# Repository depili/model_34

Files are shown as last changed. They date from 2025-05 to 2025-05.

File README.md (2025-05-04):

# Files for Model 34 tape and card punch control

The circuit is based on the example in the manual. This repository includes the hardware as a kicad project, the software for the arduino for usb serial communications and a 3d printable drive belt replacement.

The belt was printed in TPU and seems to last well, at least in light use.

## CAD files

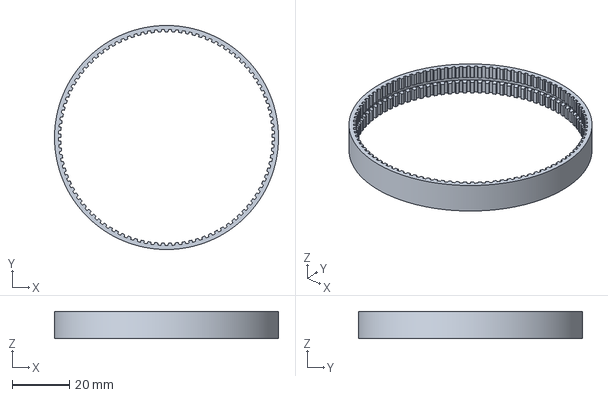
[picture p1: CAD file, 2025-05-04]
drive_belt/belt-corrected.FCStd
78.2 x 78.2 x 9.50 mm

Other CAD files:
drive_belt/belt-corrected-belt-loop.3mf

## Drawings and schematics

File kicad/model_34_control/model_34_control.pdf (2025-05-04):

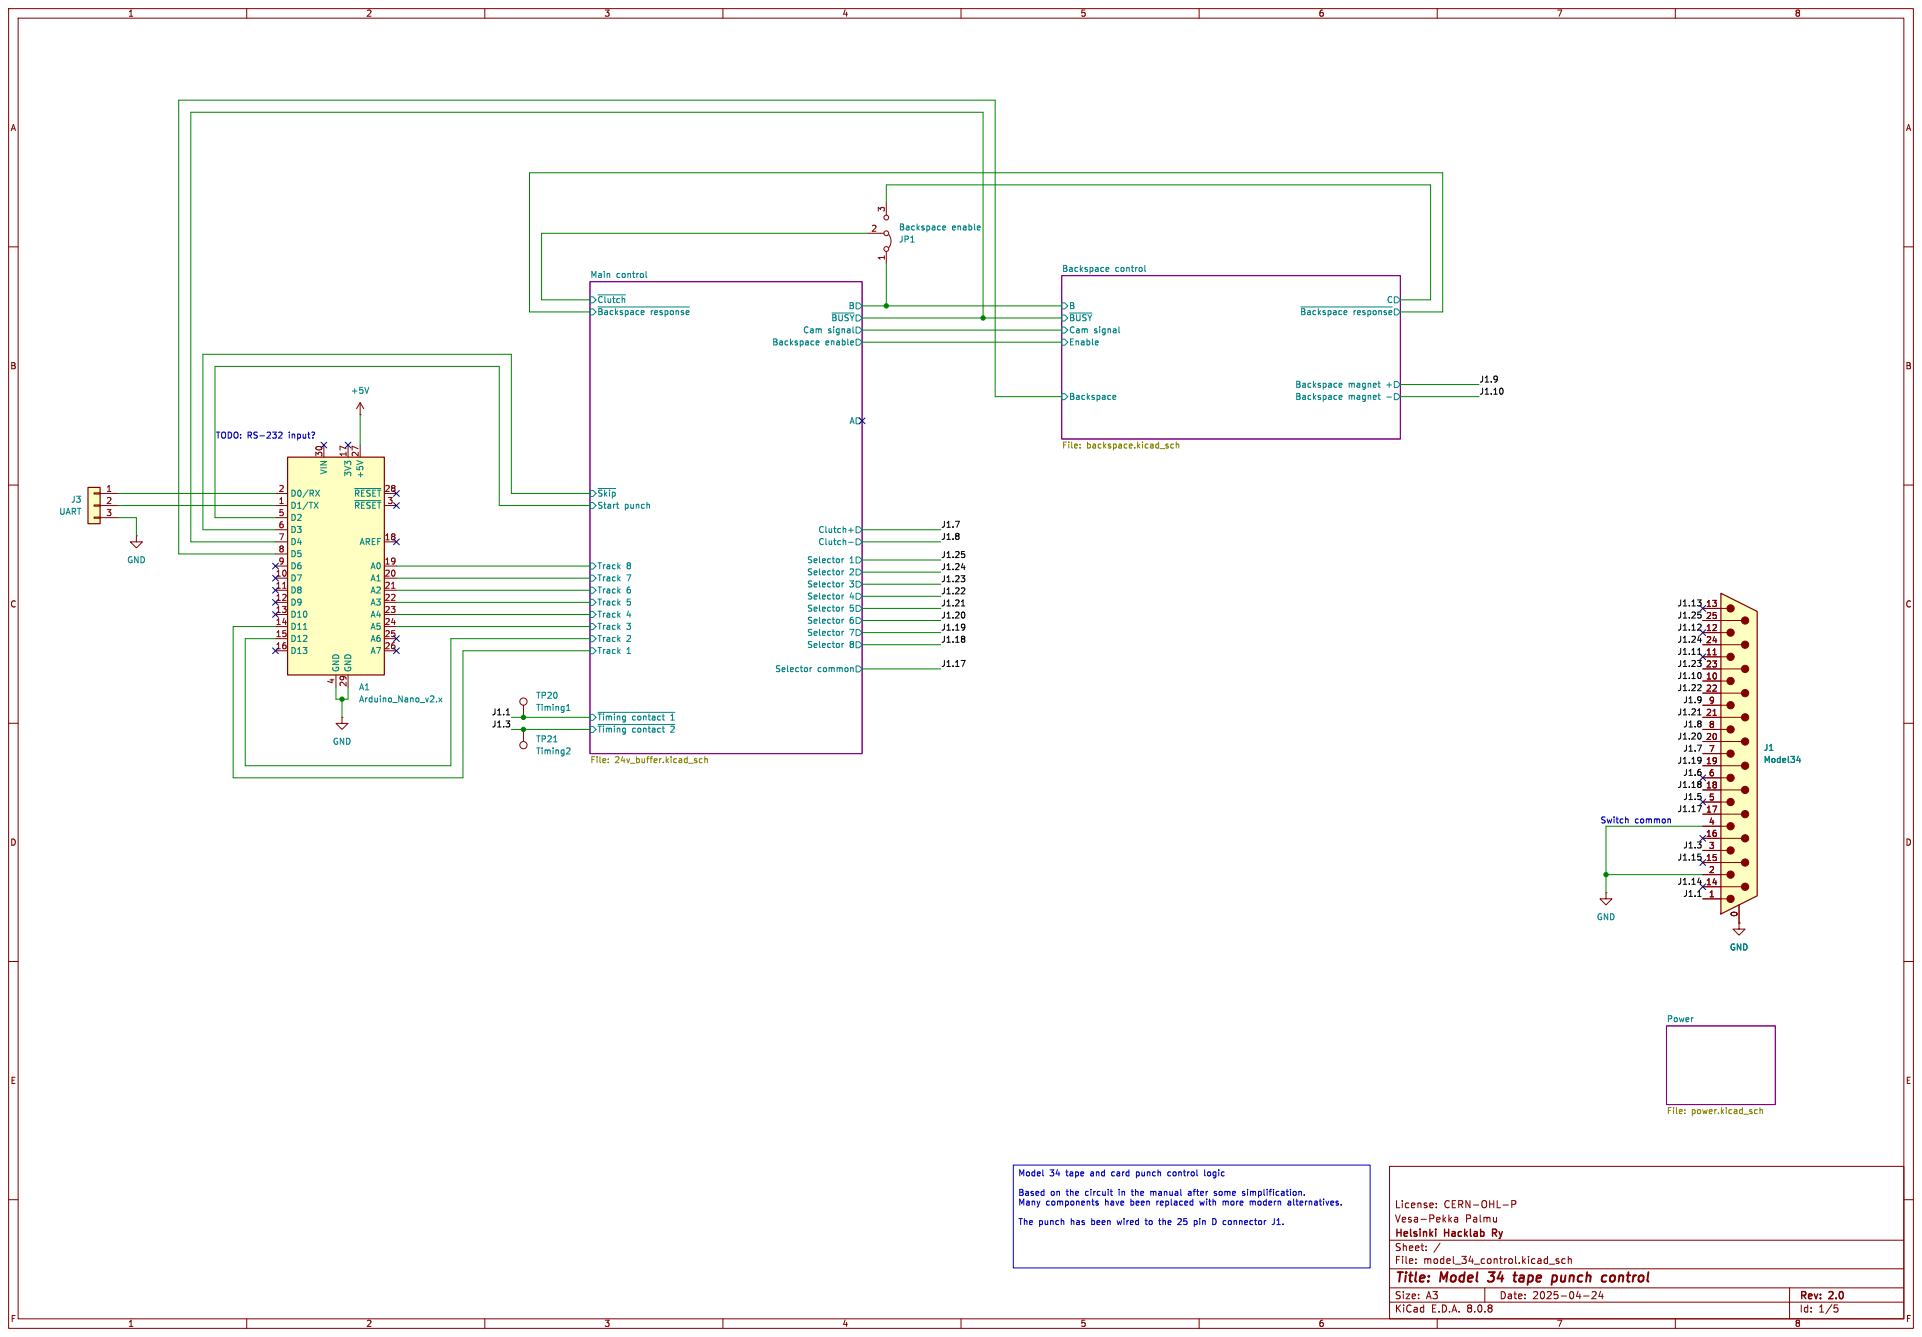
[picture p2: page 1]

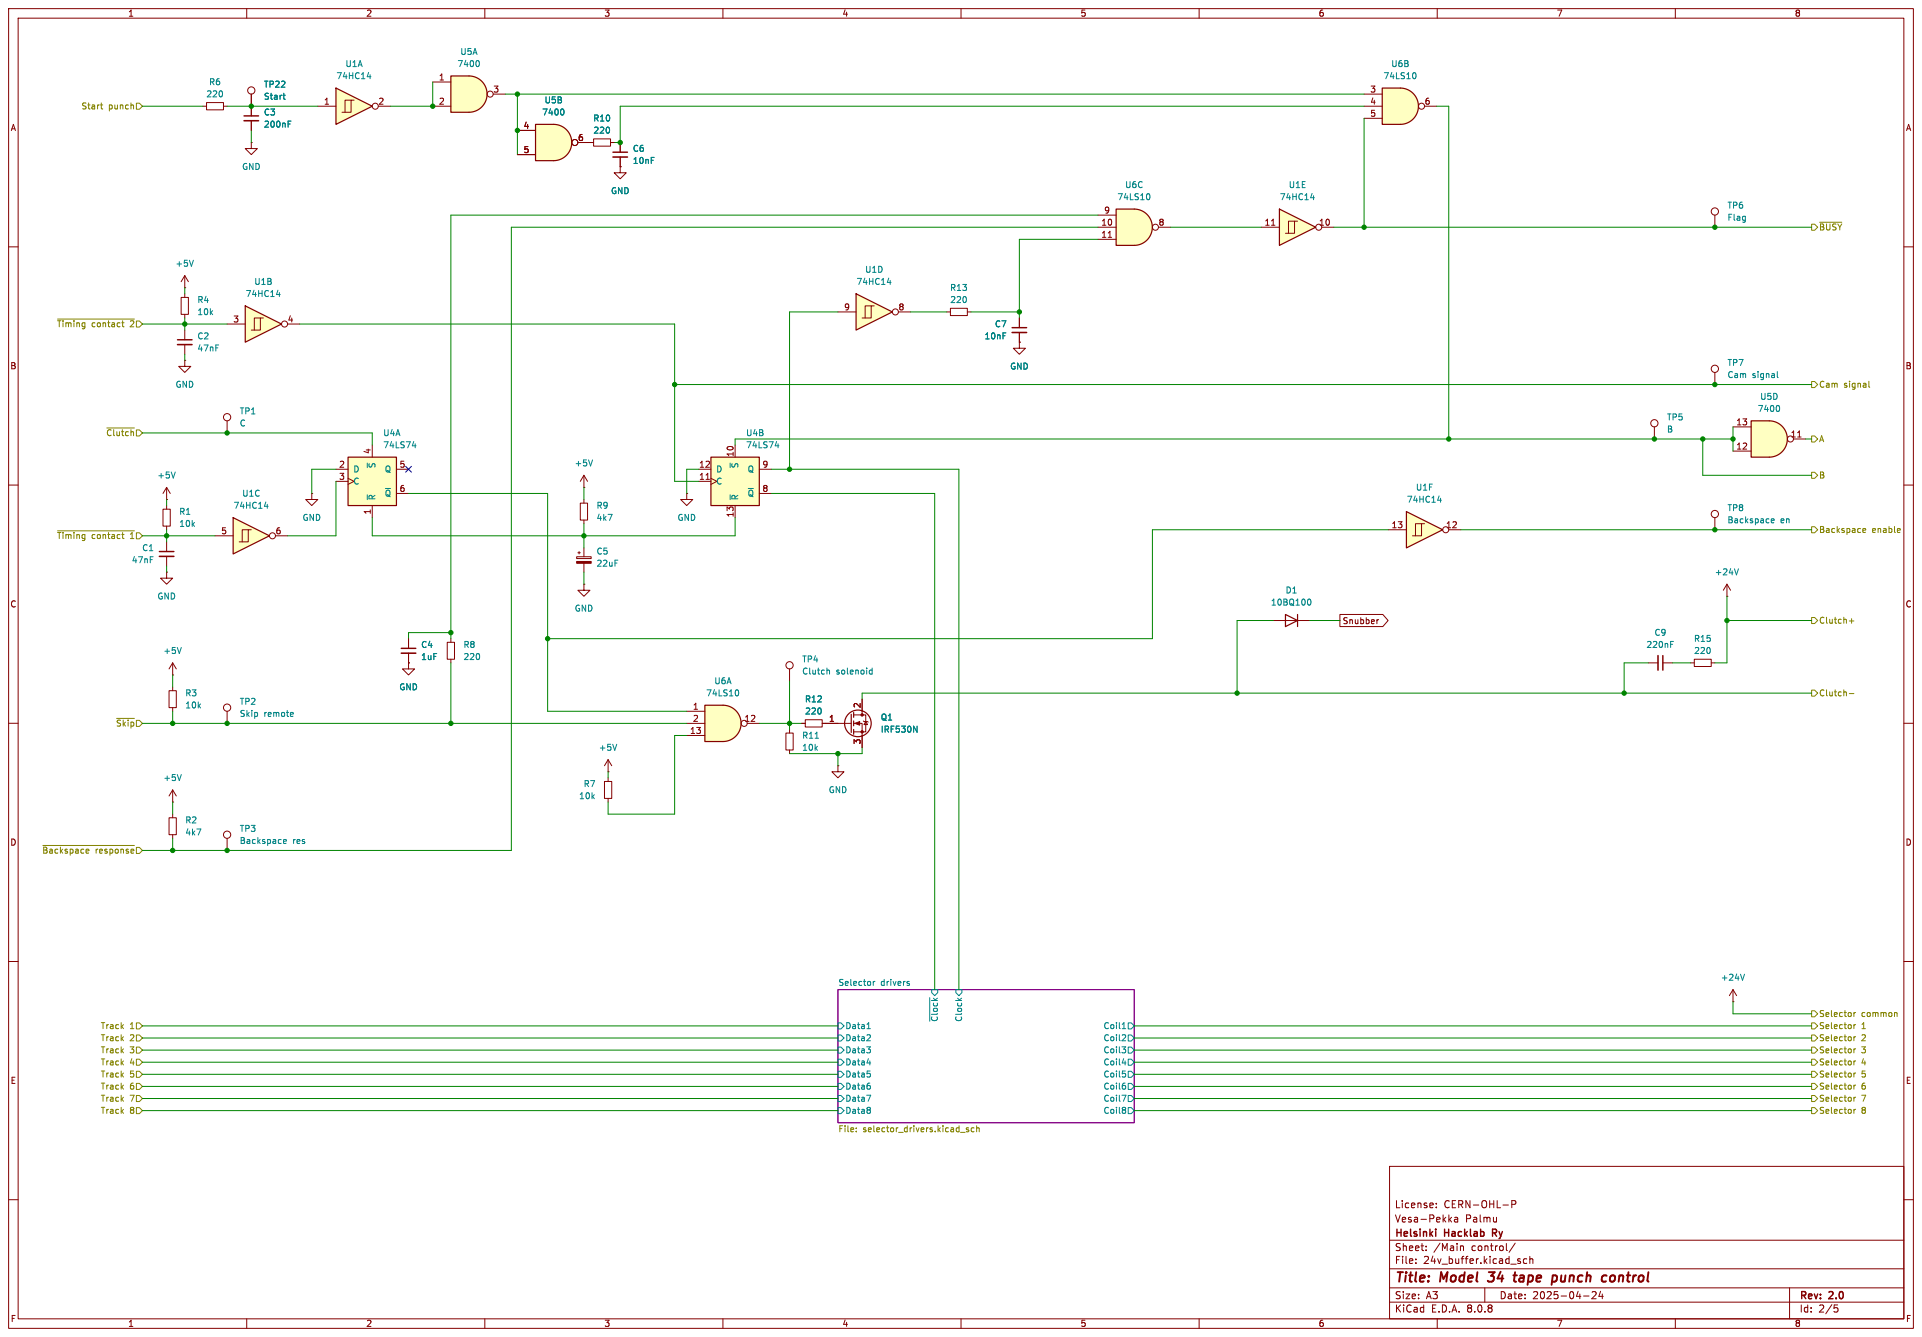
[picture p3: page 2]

TP6 Flag TP7 Cam signal TP5 B GND

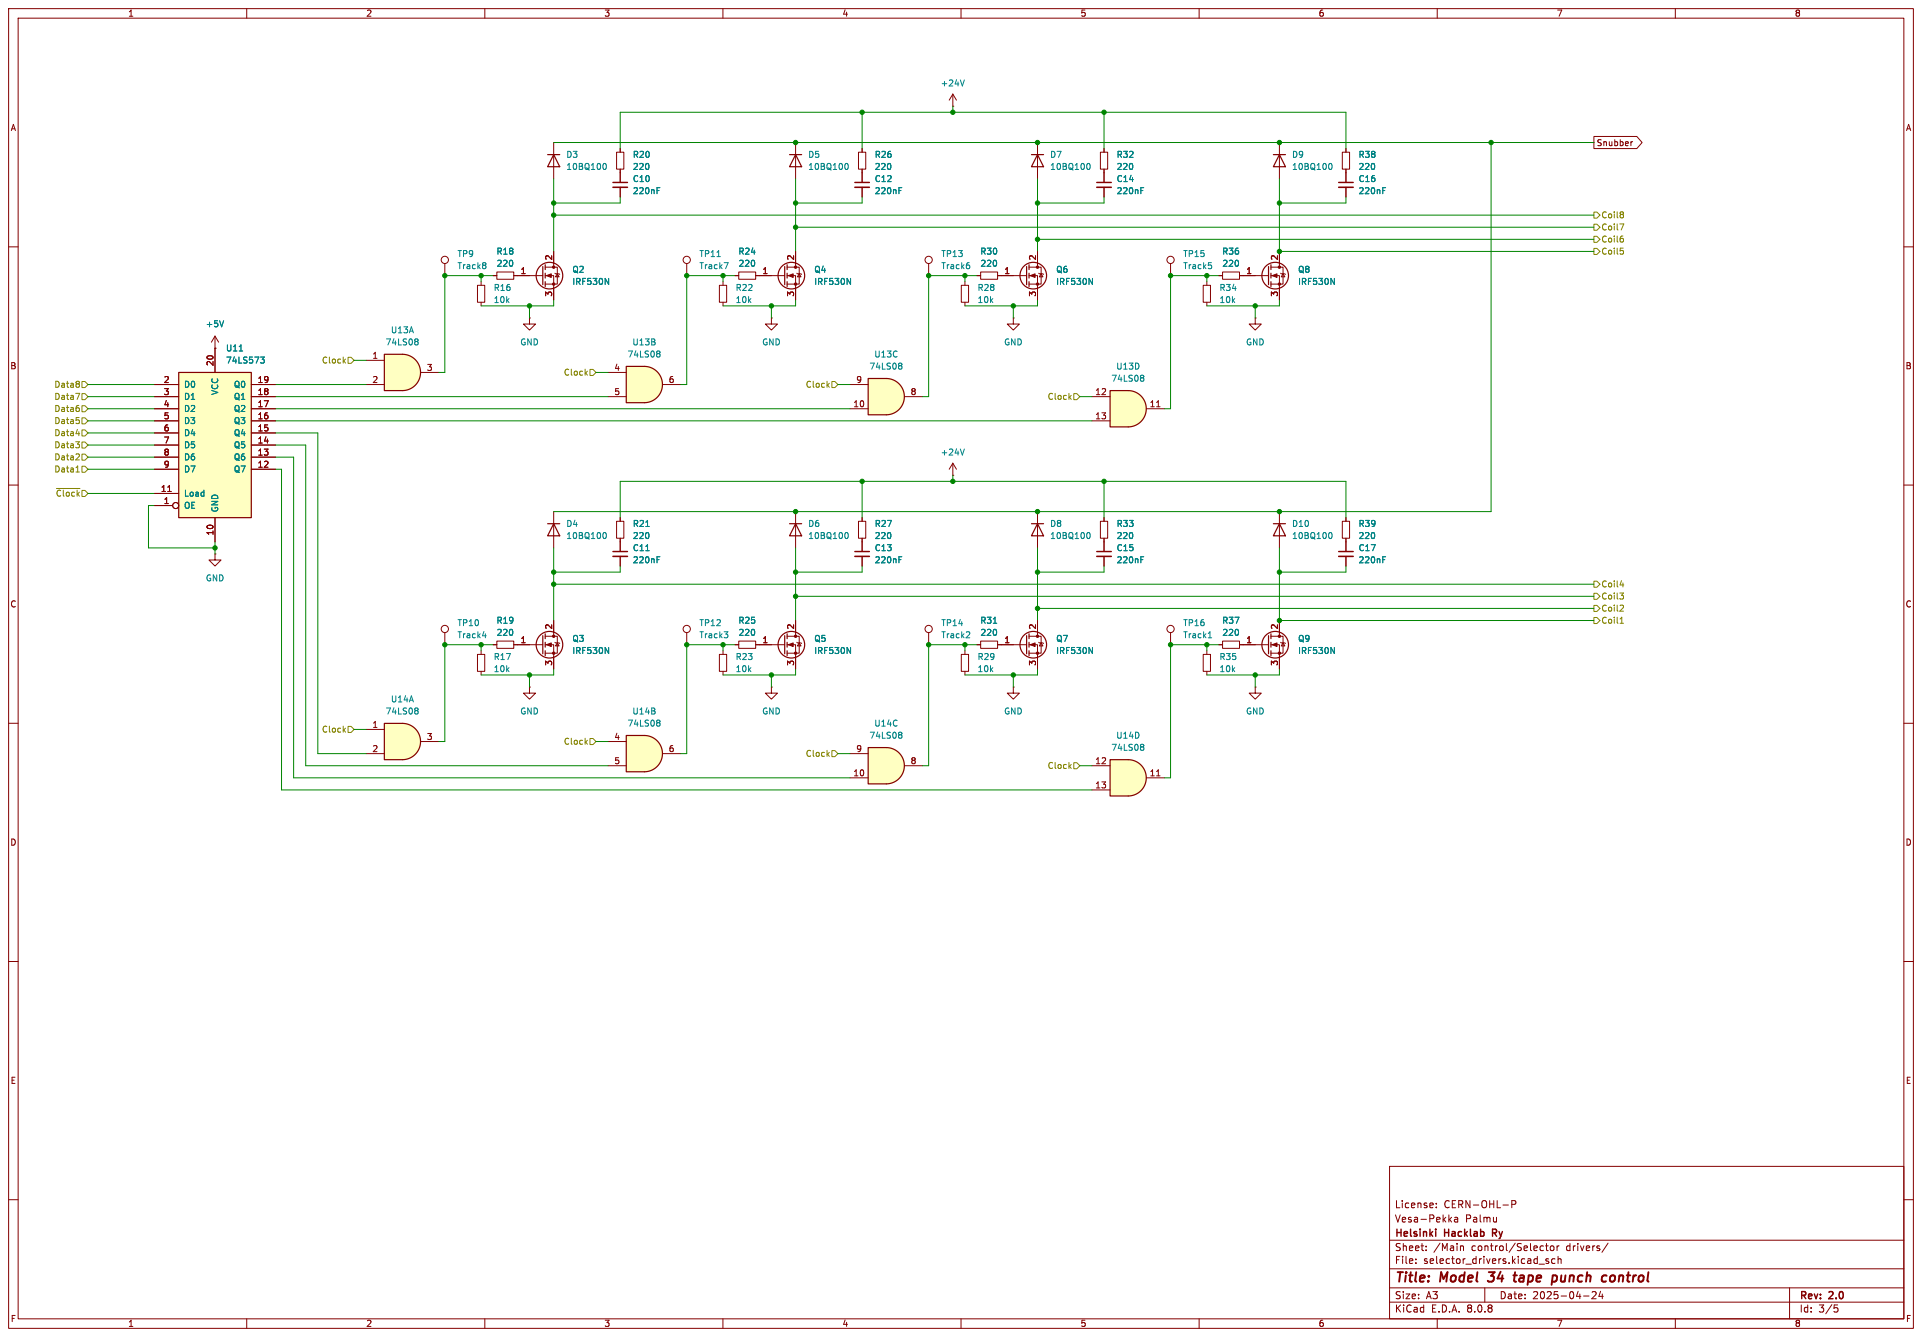
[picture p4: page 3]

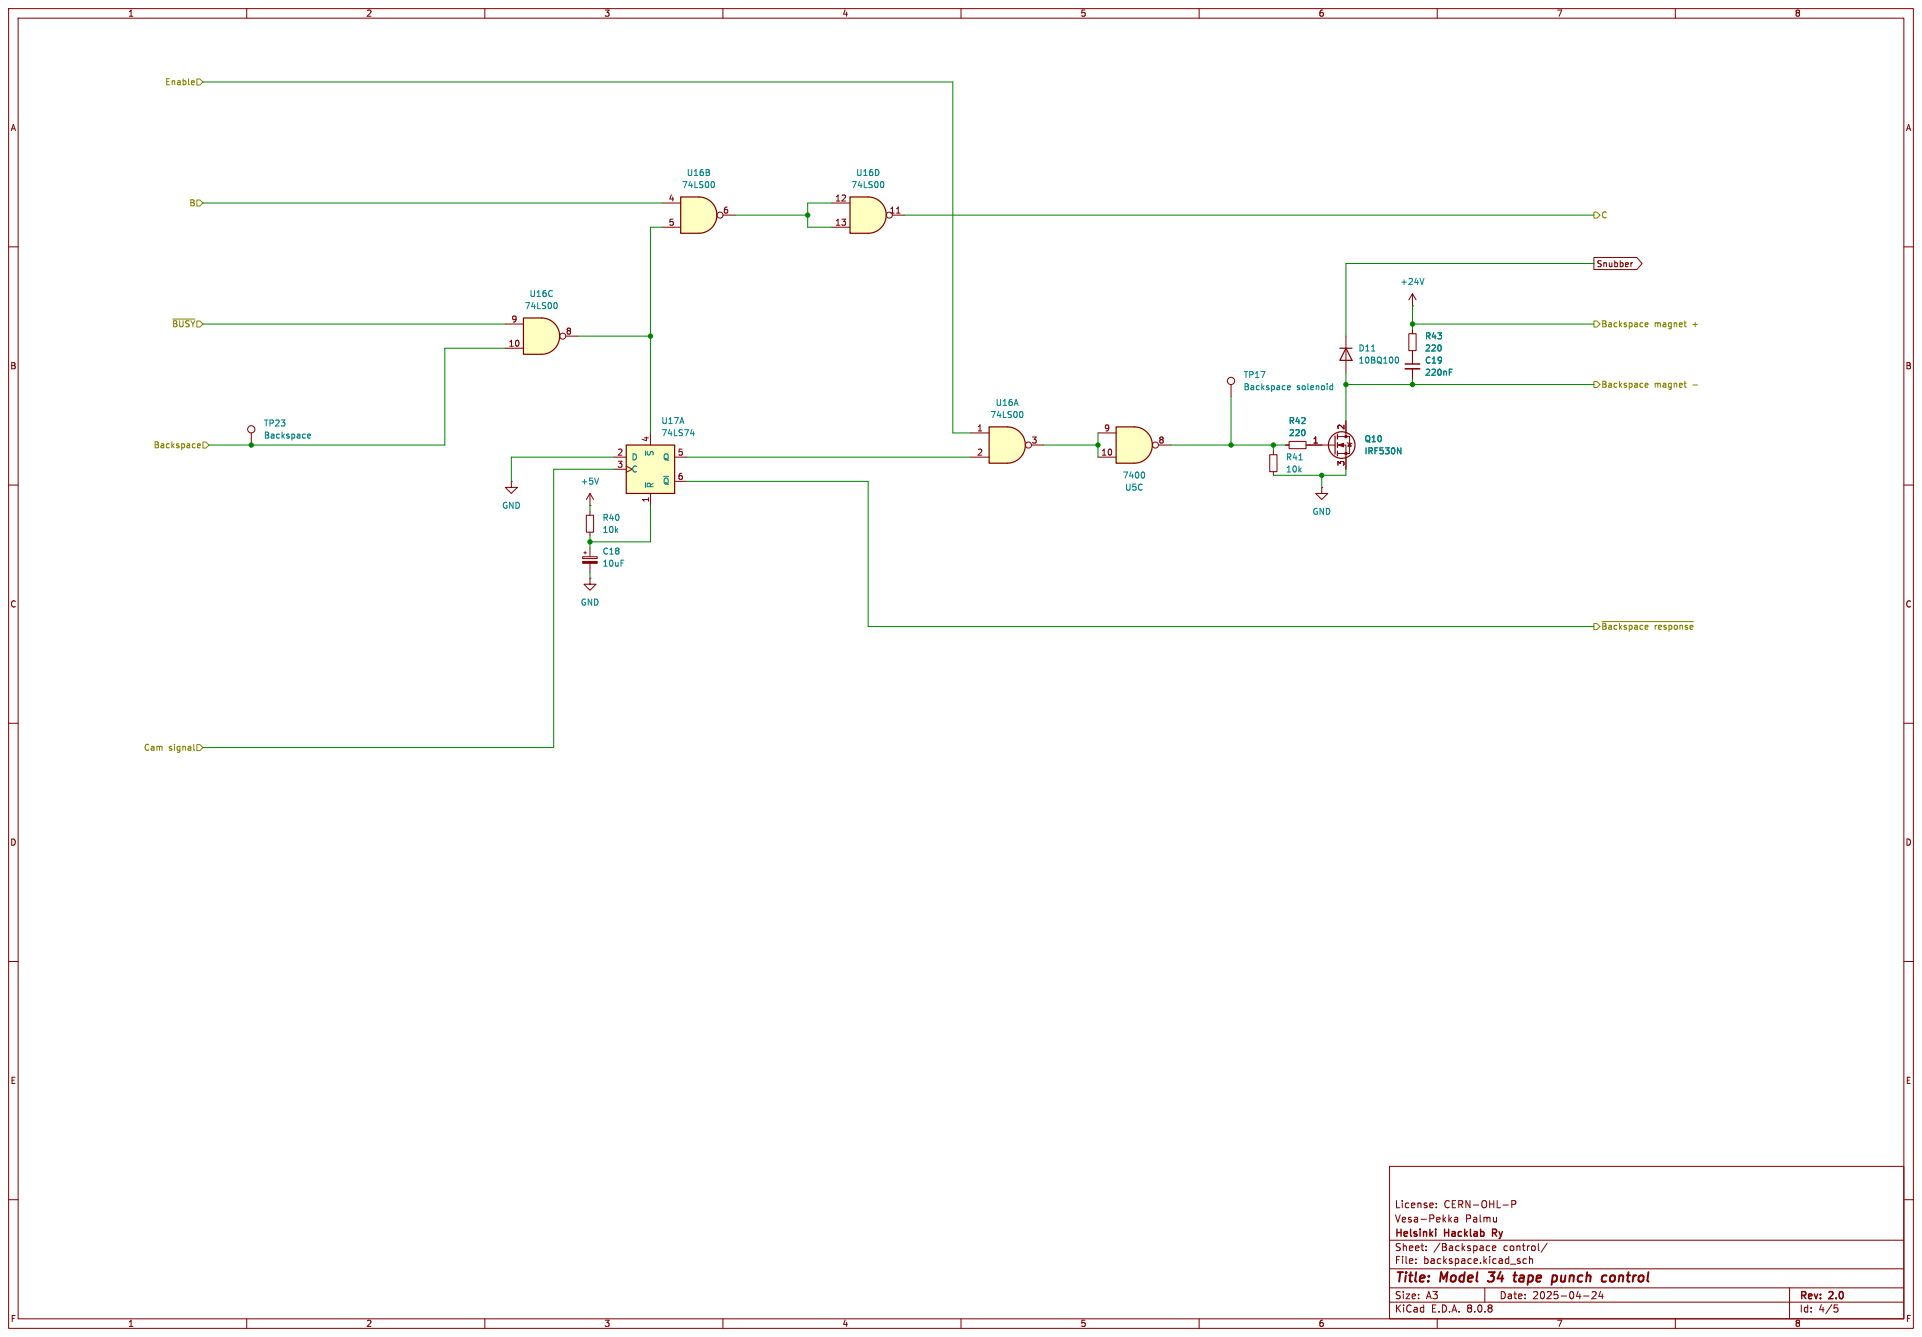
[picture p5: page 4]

Backspace EnableB Cam signal

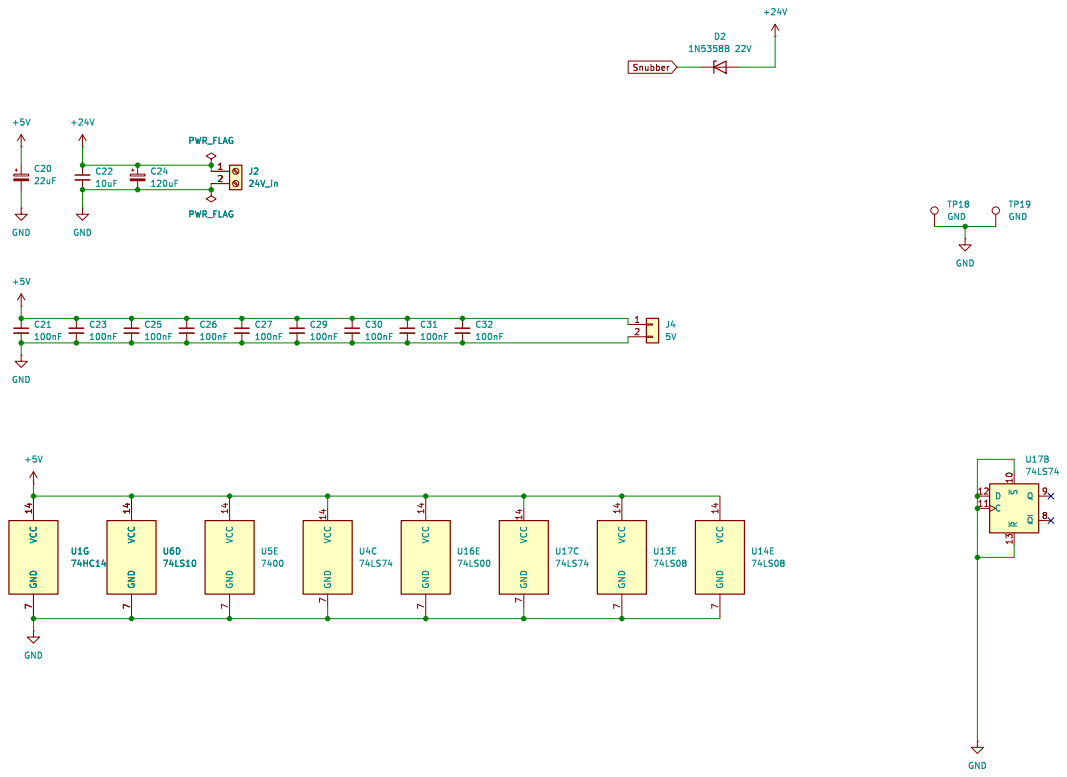
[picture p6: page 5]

License: CERN-OHL-P VCC 14 GND

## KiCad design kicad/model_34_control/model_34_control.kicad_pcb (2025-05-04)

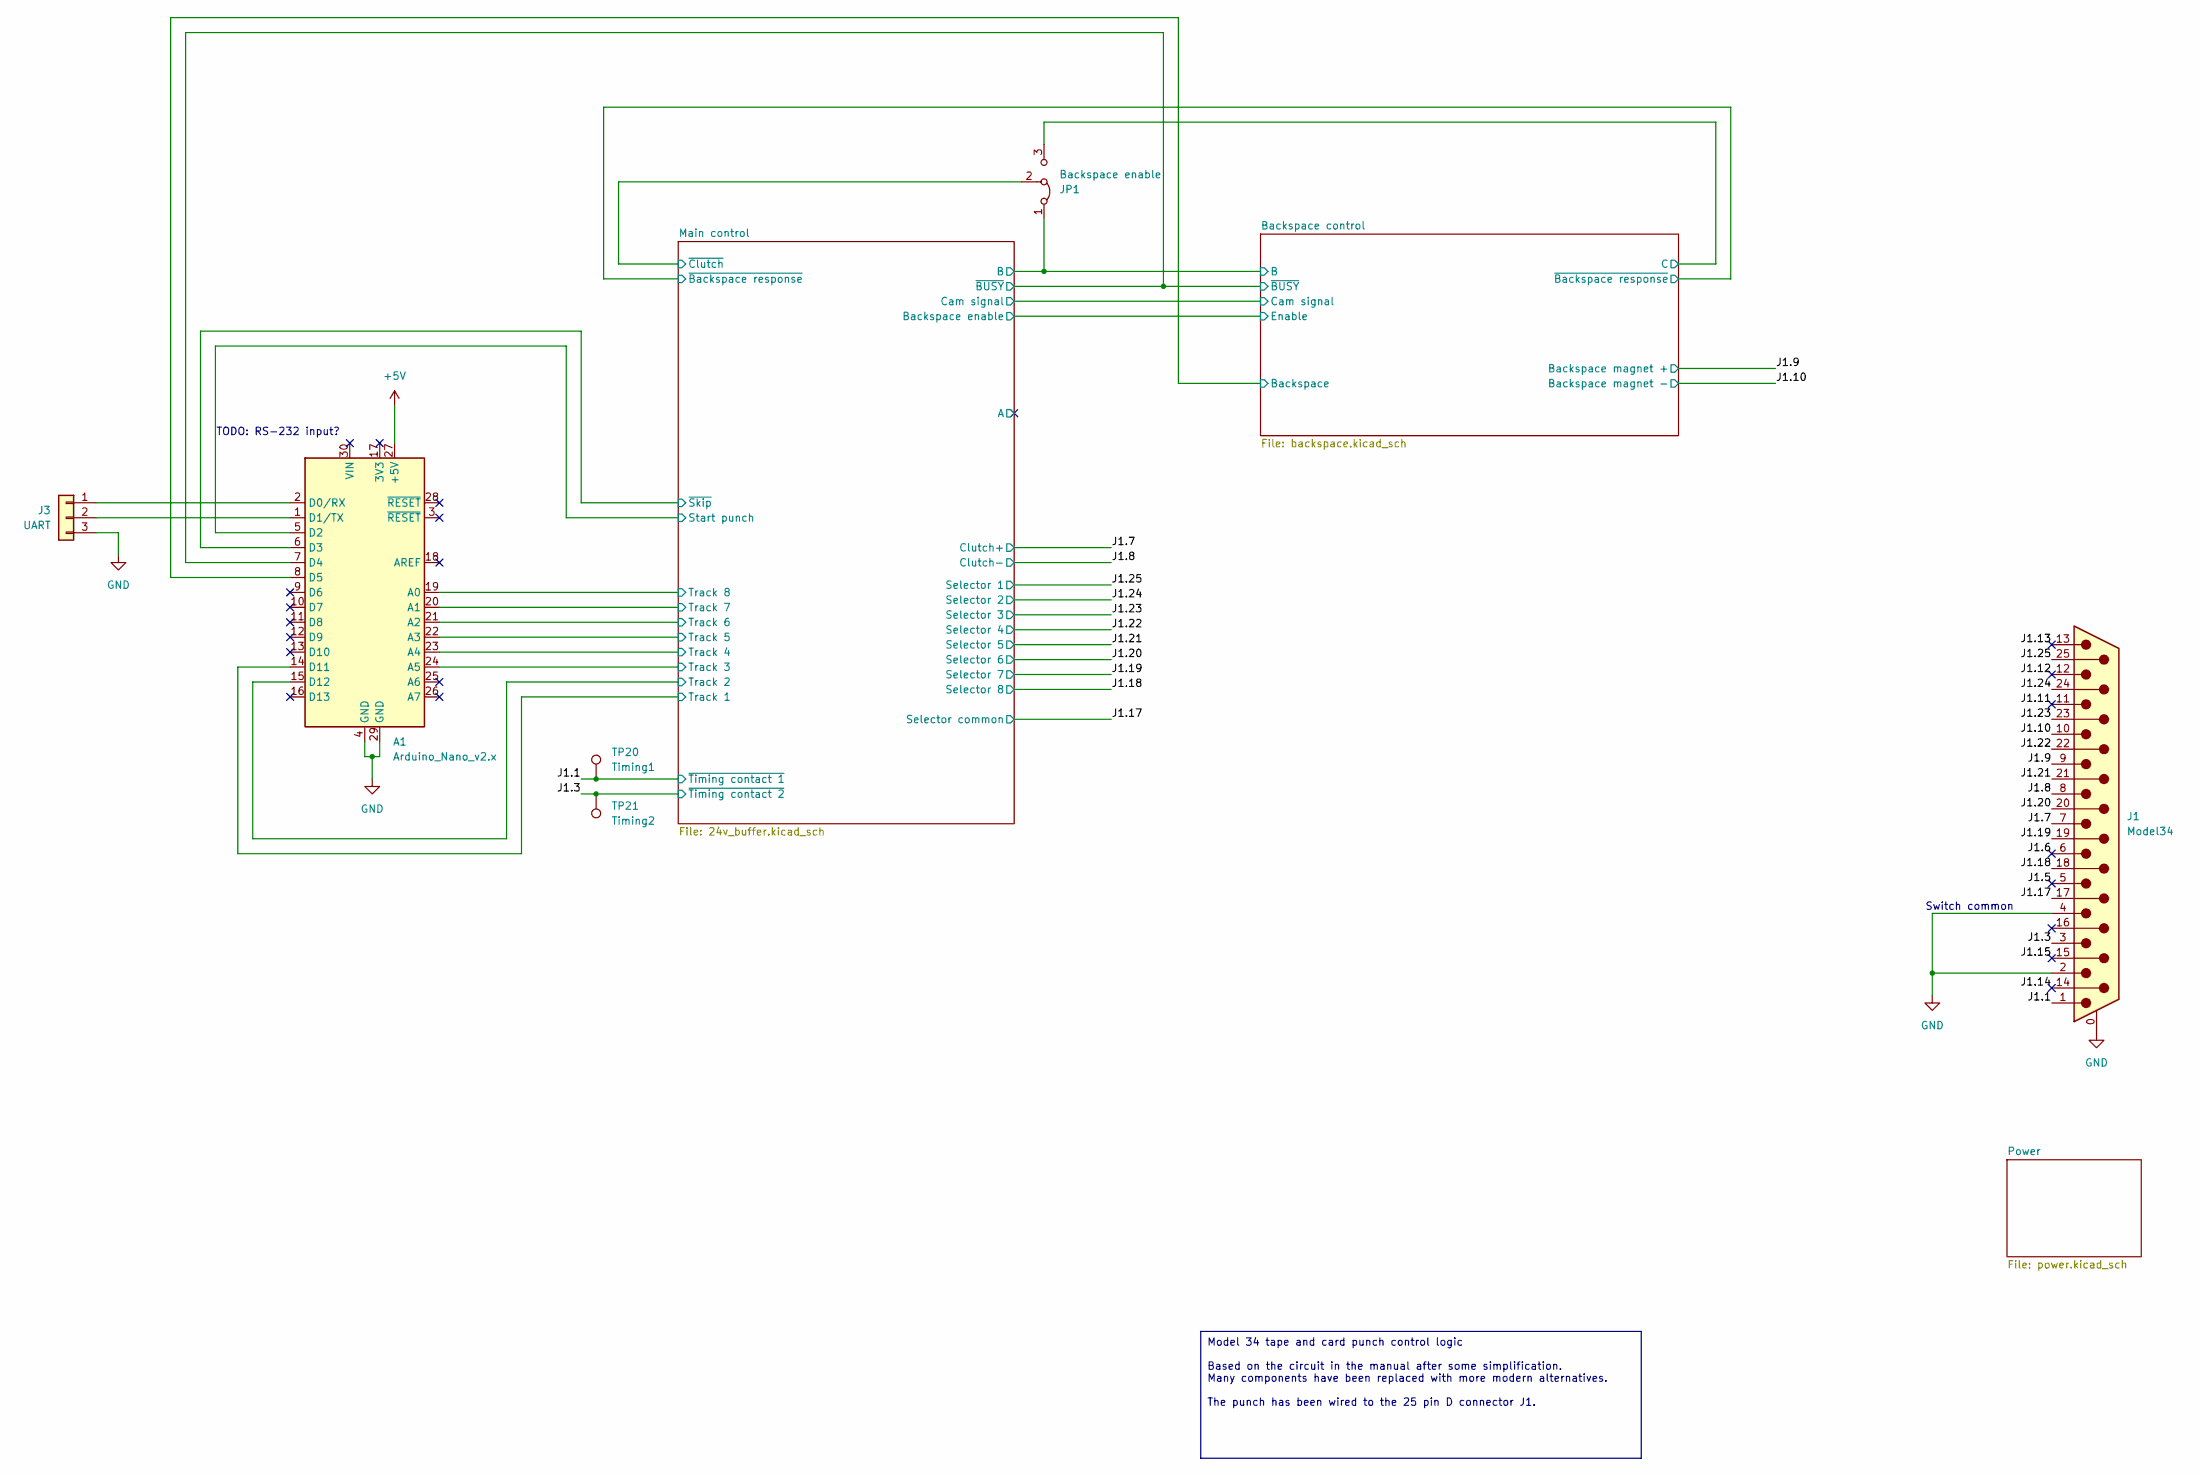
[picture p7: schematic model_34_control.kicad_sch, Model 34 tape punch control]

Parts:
A1: Arduino_Nano_v2.x; Arduino_Nano
J1: Model34; DSUB-25_Female_Horizontal_P2.77x2.84mm_EdgePinOffset9.90mm_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
J3: UART; PinHeader_1x03_P2.54mm_Vertical
JP1: Backspace enable; PinHeader_1x03_P2.54mm_Vertical
TP20: Timing1; TestPoint_Loop_D2.54mm_Drill1.5mm_Beaded
TP21: Timing2; TestPoint_Loop_D2.54mm_Drill1.5mm_Beaded

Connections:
+5V: A1.27 (+5V); also elsewhere on the board
+24V: J1.7, J1.9, J1.17; also elsewhere on the board
/Backspace control/B: JP1.1 (A); also elsewhere on the board
/Backspace control/Backspace: A1.8 (D5); also elsewhere on the board
/Backspace control/C: JP1.3 (B); also elsewhere on the board
/Backspace control/~BUSY: A1.7 (D4); also elsewhere on the board
/J1.1: J1.1, TP20.1; also elsewhere on the board
/J1.3: J1.3, TP21.1; also elsewhere on the board
/J1.5: J1.5
/J1.6: J1.6
/J1.8: J1.8; also elsewhere on the board
/J1.10: J1.10; also elsewhere on the board
/J1.11: J1.11
/J1.12: J1.12
/J1.13: J1.13
/J1.14: J1.14
/J1.15: J1.15
/J1.18: J1.18; also elsewhere on the board
/J1.19: J1.19; also elsewhere on the board
/J1.20: J1.20; also elsewhere on the board
/J1.21: J1.21; also elsewhere on the board
/J1.22: J1.22; also elsewhere on the board
/J1.23: J1.23; also elsewhere on the board
/J1.24: J1.24; also elsewhere on the board
/J1.25: J1.25; also elsewhere on the board
/Main control/Start punch: A1.5 (D2); also elsewhere on the board
/Main control/Track 1: A1.14 (D11); also elsewhere on the board
/Main control/Track 2: A1.15 (D12); also elsewhere on the board
/Main control/Track 3: A1.24 (A5); also elsewhere on the board
/Main control/Track 4: A1.23 (A4); also elsewhere on the board
/Main control/Track 5: A1.22 (A3); also elsewhere on the board
/Main control/Track 6: A1.21 (A2); also elsewhere on the board
/Main control/Track 7: A1.20 (A1); also elsewhere on the board
/Main control/Track 8: A1.19 (A0); also elsewhere on the board
/Main control/~Clutch: JP1.2 (C); also elsewhere on the board
/Main control/~Skip: A1.6 (D3); also elsewhere on the board
GND: A1.4 (GND), A1.29 (GND), J1.0 (PAD), J1.2, J1.4, J3.3; also elsewhere on the board
unnamed: A1.2 (D0/RX), J3.1
unnamed: A1.1 (D1/TX), J3.2

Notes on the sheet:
Model 34 tape and card punch control logic Based on the circuit in the manual after some simplification. Many components have been replaced with more modern alternatives. The punch has been wired to the 25 pin D connector J1.
TODO: RS-232 input?
Switch common

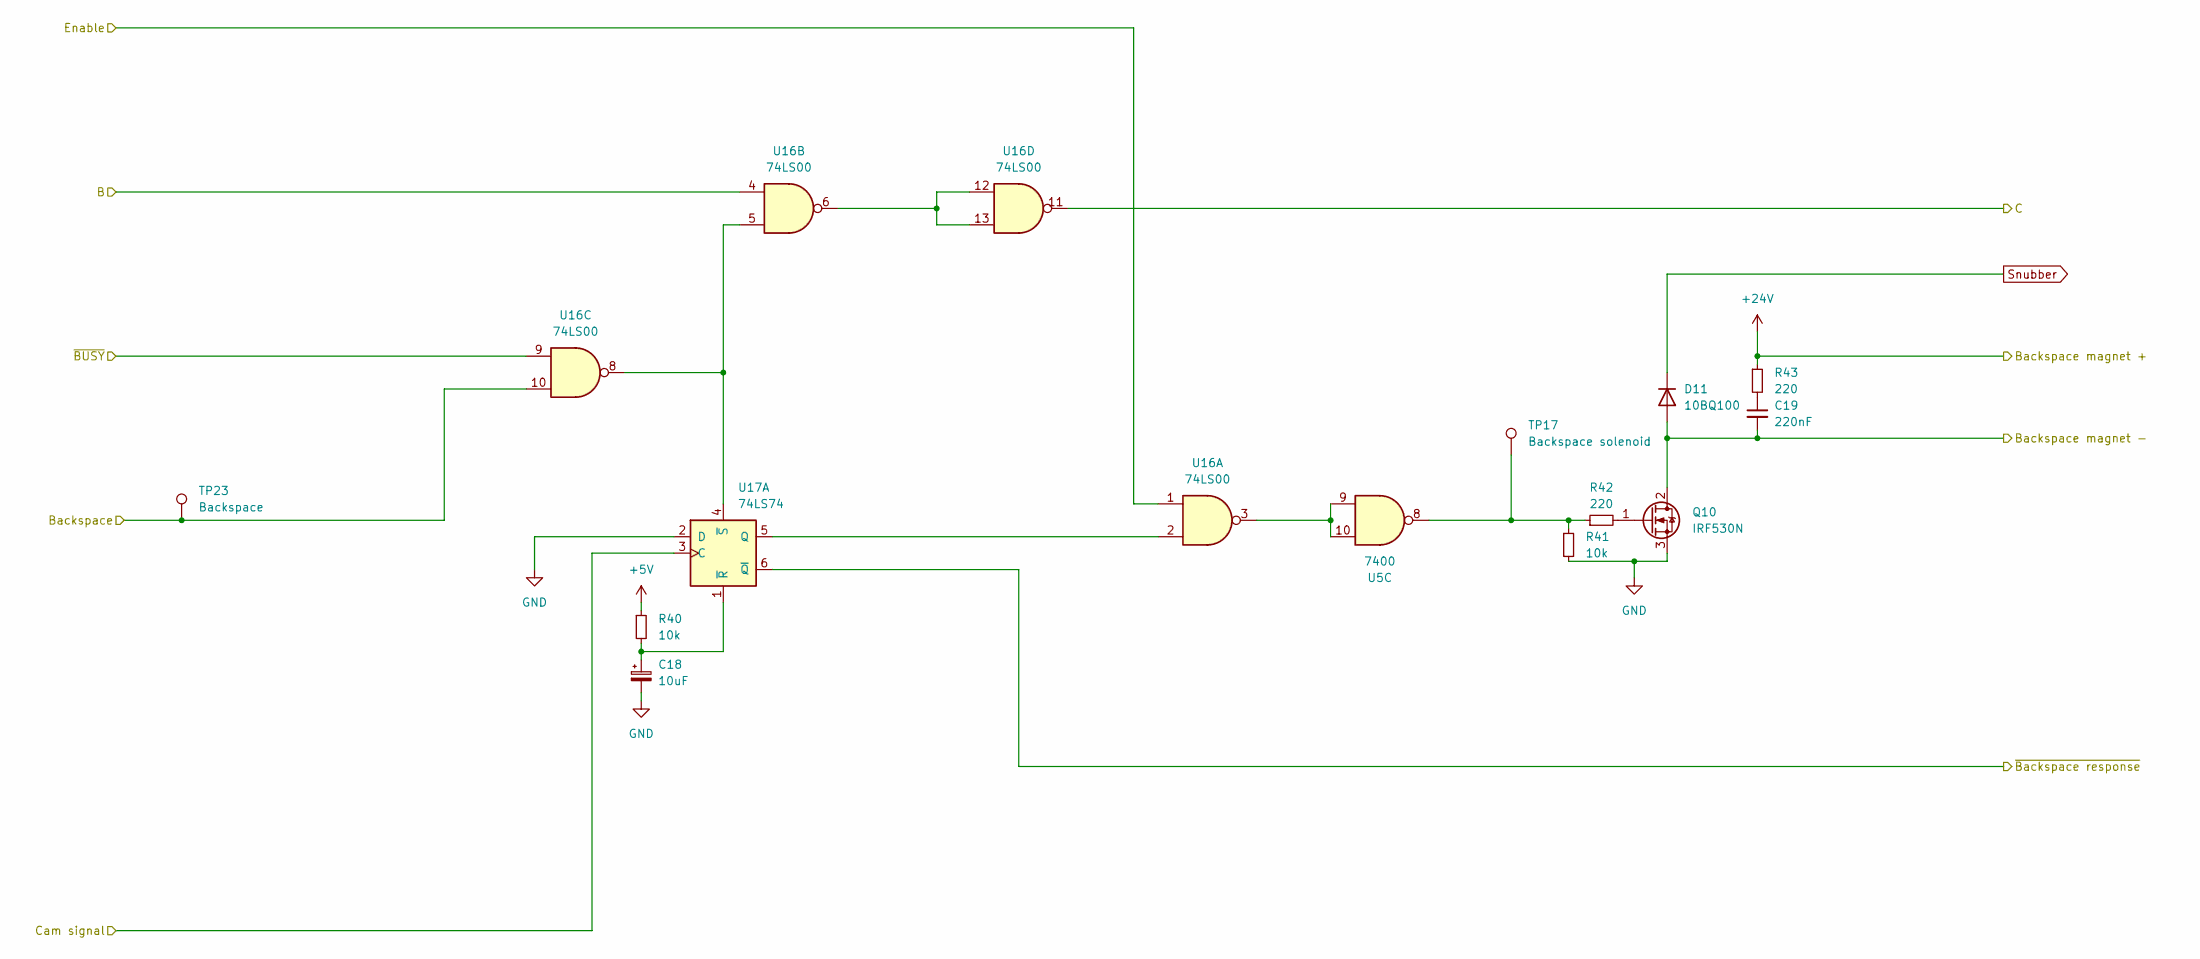
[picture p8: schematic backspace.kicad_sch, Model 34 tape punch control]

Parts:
C18: 10uF; CP_EIA-3528-21_Kemet-B_Pad1.50x2.35mm_HandSolder
C19: 220nF; C_0805_2012Metric_Pad1.18x1.45mm_HandSolder
D11: 10BQ100; D_SMA-SMB_Universal_Handsoldering
Q10: IRF530N; TO-220-3_Vertical
R40, R41: 10k; R_0805_2012Metric_Pad1.20x1.40mm_HandSolder
R42, R43: 220; R_0805_2012Metric_Pad1.20x1.40mm_HandSolder
TP17: Backspace solenoid; TestPoint_Loop_D2.54mm_Drill1.5mm_Beaded
TP23: Backspace; TestPoint_Loop_D2.54mm_Drill1.5mm_Beaded
U5: 7400; SOIC-14_3.9x8.7mm_P1.27mm
U16: 74LS00; SOIC-14_3.9x8.7mm_P1.27mm
U17: 74LS74; SOIC-14_3.9x8.7mm_P1.27mm

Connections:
+5V: R40.1; also elsewhere on the board
+24V: R43.1; also elsewhere on the board
/Backspace control/B: U16.4; also elsewhere on the board
/Backspace control/Backspace: TP23.1, U16.10; also elsewhere on the board
/Backspace control/C: U16.11; also elsewhere on the board
/Backspace control/Cam signal: U17.3 (C); also elsewhere on the board
/Backspace control/Enable: U16.1; also elsewhere on the board
/Backspace control/~BUSY: U16.9; also elsewhere on the board
/Backspace control/~Backspace response: U17.6 (~Q); also elsewhere on the board
/J1.10: C19.2, D11.2 (A), Q10.2 (D); also elsewhere on the board
GND: C18.2, Q10.3 (S), R41.2, U17.2 (D); also elsewhere on the board
unnamed: C19.1, R43.2
unnamed: Q10.1 (G), R42.2
unnamed: R41.1, R42.1, TP17.1, U5.8
unnamed: U5.9, U5.10, U16.3
unnamed: U16.6, U16.12, U16.13
unnamed: U16.2, U17.5 (Q)
unnamed: C18.1, R40.2, U17.1 (~R)
unnamed: U16.5, U16.8, U17.4 (~S)
Snubber: D11.1 (K); also elsewhere on the board

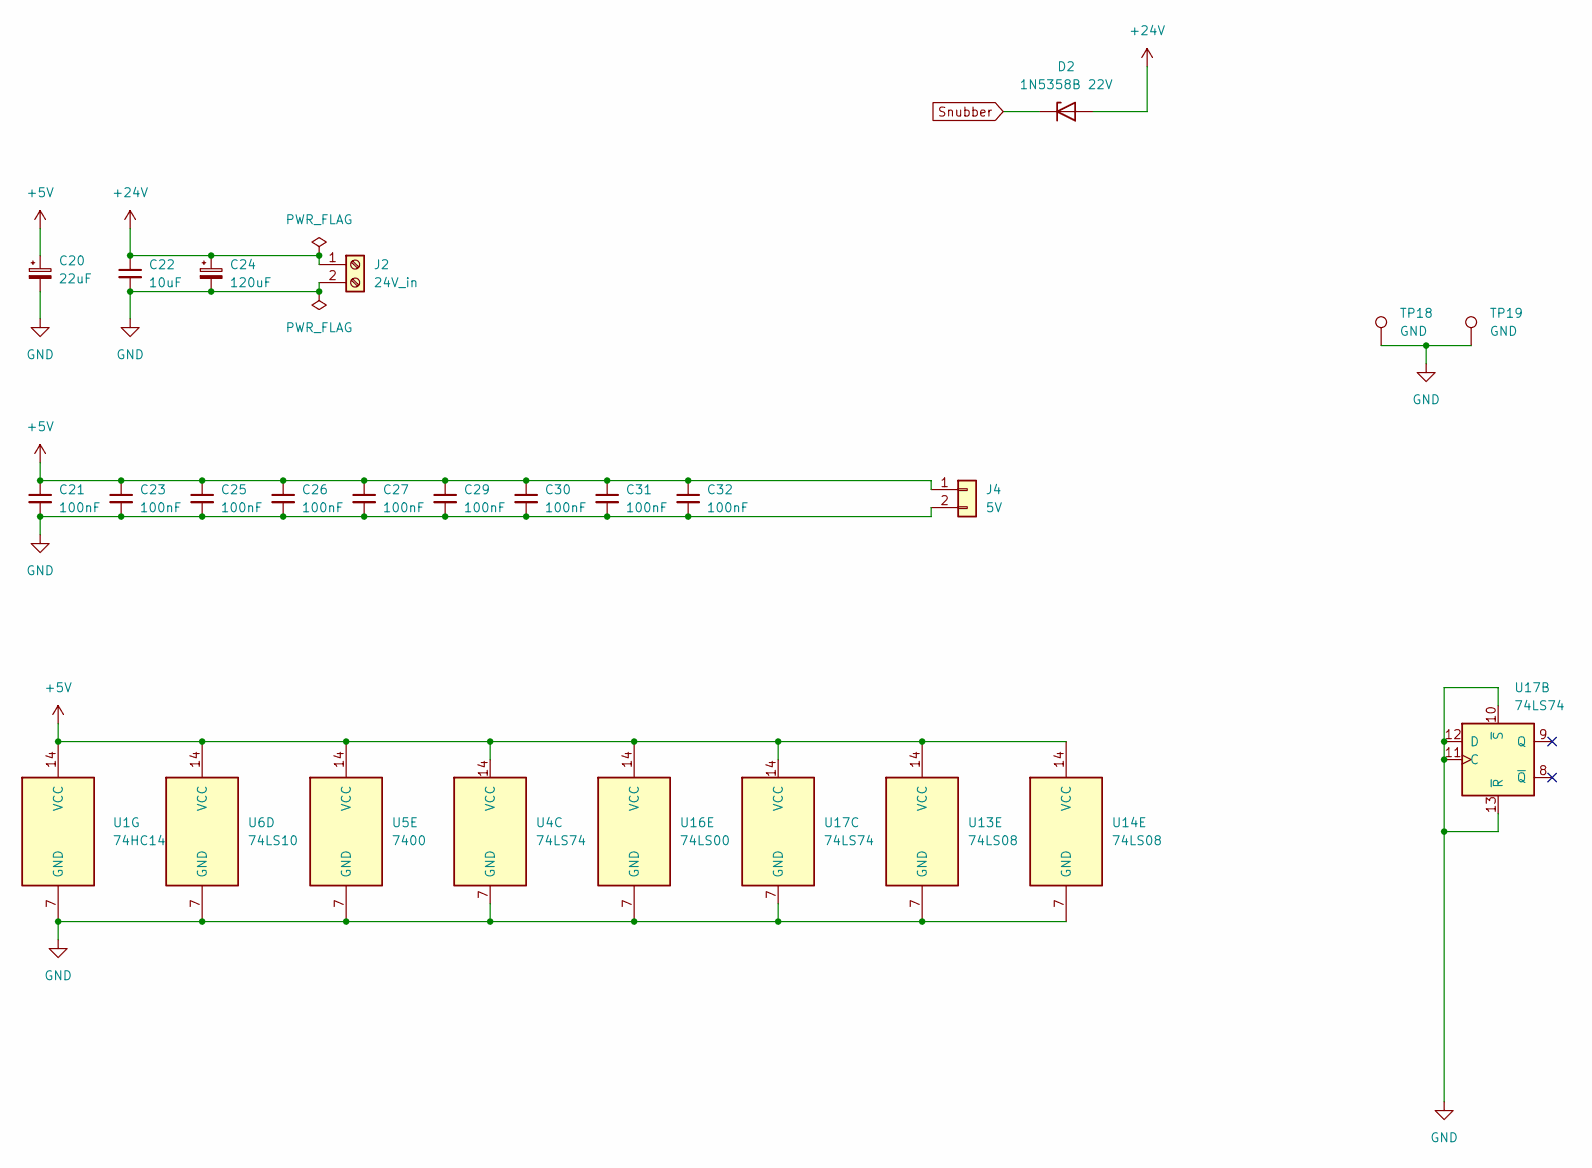
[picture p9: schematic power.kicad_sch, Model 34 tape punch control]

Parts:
C20: 22uF; CP_EIA-3528-21_Kemet-B_Pad1.50x2.35mm_HandSolder
C21, C23, C25, C26, C27, C29, C30, C31, C32: 100nF; C_0805_2012Metric_Pad1.18x1.45mm_HandSolder
C22: 10uF; C_1206_3216Metric_Pad1.33x1.80mm_HandSolder
C24: 120uF; CP_Elec_10x10.5
D2: 1N5358B 22V; D_DO-201AE_P15.24mm_Horizontal
J2: 24V_in; TerminalBlock_MetzConnect_Type073_RT02602HBLU_1x02_P5.08mm_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
J4: 5V; PinHeader_1x02_P2.54mm_Vertical
TP18, TP19: GND; TestPoint_Loop_D2.54mm_Drill1.5mm_Beaded
U1: 74HC14; SOIC-14_3.9x8.7mm_P1.27mm
U4, U17: 74LS74; SOIC-14_3.9x8.7mm_P1.27mm
U5: 7400; SOIC-14_3.9x8.7mm_P1.27mm
U6: 74LS10; SOIC-14_3.9x8.7mm_P1.27mm
U13, U14: 74LS08; SOIC-14_3.9x8.7mm_P1.27mm
U16: 74LS00; SOIC-14_3.9x8.7mm_P1.27mm

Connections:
+5V: C20.1, C21.1, C23.1, C25.1, C26.1, C27.1, C29.1, C30.1, C31.1, C32.1, J4.1, U1.14 (VCC), U4.14 (VCC), U5.14 (VCC), U6.14 (VCC), U13.14 (VCC), U14.14 (VCC), U16.14 (VCC), U17.14 (VCC); also elsewhere on the board
+24V: C22.1, C24.1, D2.2 (A), J2.1; also elsewhere on the board
GND: C20.2, C21.2, C22.2, C23.2, C24.2, C25.2, C26.2, C27.2, C29.2, C30.2, C31.2, C32.2, J2.2, J4.2, TP18.1, TP19.1, U1.7 (GND), U4.7 (GND), U5.7 (GND), U6.7 (GND), U13.7 (GND), U14.7 (GND), U16.7 (GND), U17.7 (GND), U17.10 (~S), U17.11 (C), U17.12 (D), U17.13 (~R); also elsewhere on the board
Snubber: D2.1 (K); also elsewhere on the board

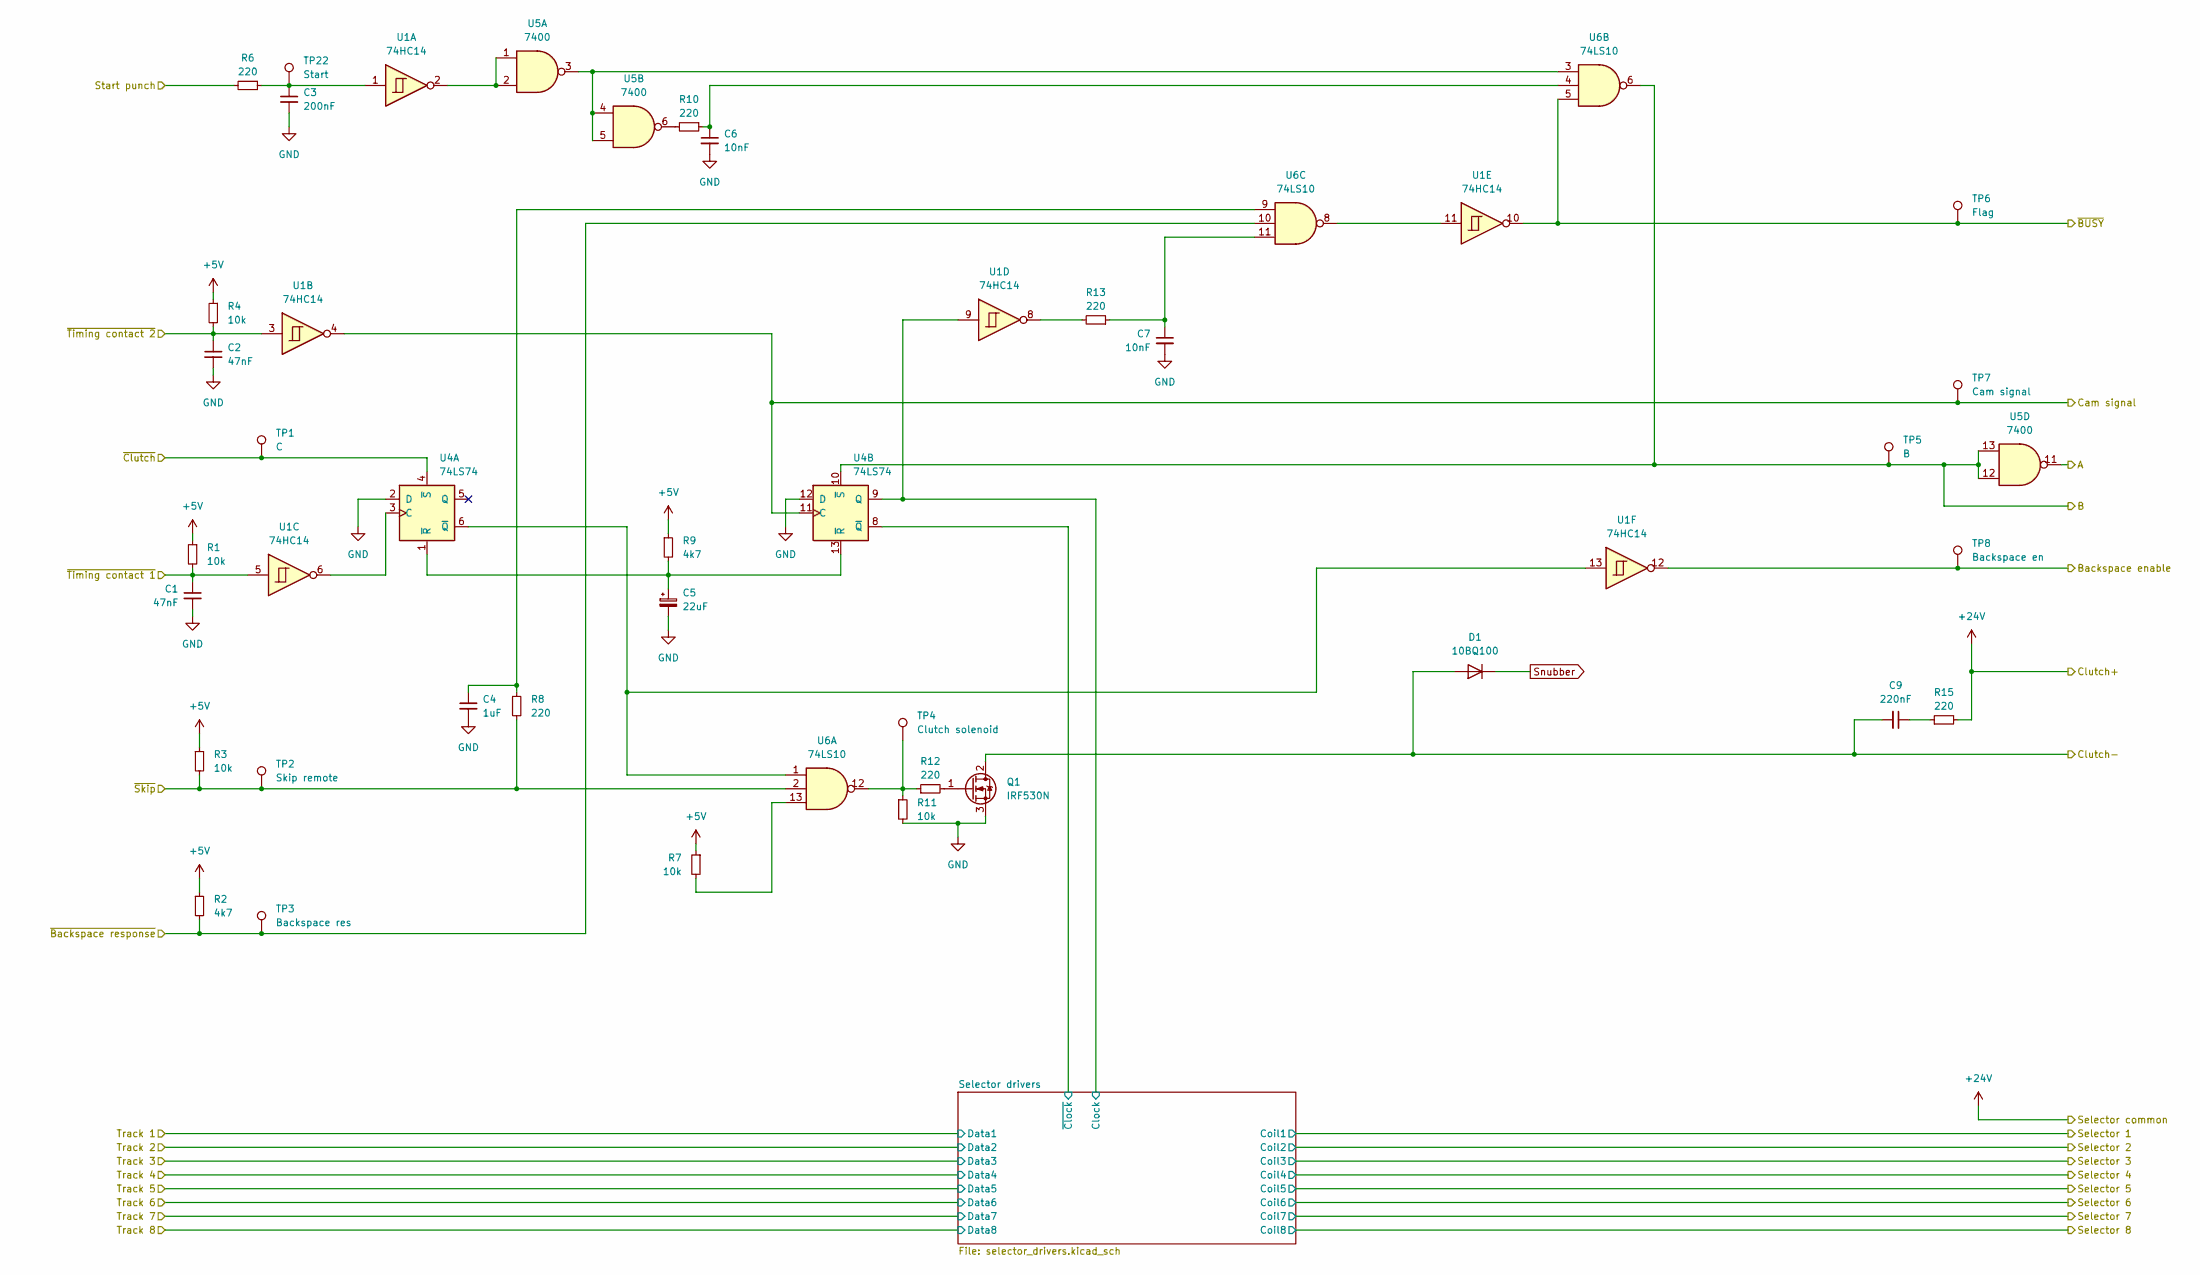
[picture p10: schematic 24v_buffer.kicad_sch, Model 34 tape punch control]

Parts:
C1, C2: 47nF; C_0805_2012Metric_Pad1.18x1.45mm_HandSolder
C3: 200nF; C_0805_2012Metric_Pad1.18x1.45mm_HandSolder
C4: 1uF; C_0805_2012Metric_Pad1.18x1.45mm_HandSolder
C5: 22uF; CP_EIA-3528-21_Kemet-B_Pad1.50x2.35mm_HandSolder
C6, C7: 10nF; C_0805_2012Metric_Pad1.18x1.45mm_HandSolder
C9: 220nF; C_0805_2012Metric_Pad1.18x1.45mm_HandSolder
D1: 10BQ100; D_SMA-SMB_Universal_Handsoldering
Q1: IRF530N; TO-220-3_Vertical
R1, R3, R4, R7, R11: 10k; R_0805_2012Metric_Pad1.20x1.40mm_HandSolder
R2, R9: 4k7; R_0805_2012Metric_Pad1.20x1.40mm_HandSolder
R6, R8, R10, R12, R13, R15: 220; R_0805_2012Metric_Pad1.20x1.40mm_HandSolder
TP1: C; TestPoint_Loop_D2.54mm_Drill1.5mm_Beaded
TP2: Skip remote; TestPoint_Loop_D2.54mm_Drill1.5mm_Beaded
TP3: Backspace res; TestPoint_Loop_D2.54mm_Drill1.5mm_Beaded
TP4: Clutch solenoid; TestPoint_Loop_D2.54mm_Drill1.5mm_Beaded
TP5: B; TestPoint_Loop_D2.54mm_Drill1.5mm_Beaded
TP6: Flag; TestPoint_Loop_D2.54mm_Drill1.5mm_Beaded
TP7: Cam signal; TestPoint_Loop_D2.54mm_Drill1.5mm_Beaded
TP8: Backspace en; TestPoint_Loop_D2.54mm_Drill1.5mm_Beaded
TP22: Start; TestPoint_Loop_D2.54mm_Drill1.5mm_Beaded
U1: 74HC14; SOIC-14_3.9x8.7mm_P1.27mm
U4: 74LS74; SOIC-14_3.9x8.7mm_P1.27mm
U5: 7400; SOIC-14_3.9x8.7mm_P1.27mm
U6: 74LS10; SOIC-14_3.9x8.7mm_P1.27mm

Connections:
+5V: R1.1, R2.1, R3.1, R4.1, R7.1, R9.1; also elsewhere on the board
+24V: R15.2; also elsewhere on the board
/Backspace control/B: TP5.1, U4.10 (~S), U5.12, U5.13, U6.6; also elsewhere on the board
/Backspace control/Cam signal: TP7.1, U1.4, U4.11 (C); also elsewhere on the board
/Backspace control/Enable: TP8.1, U1.12; also elsewhere on the board
/Backspace control/~BUSY: TP6.1, U1.10, U6.5; also elsewhere on the board
/Backspace control/~Backspace response: R2.2, TP3.1, U6.10; also elsewhere on the board
/J1.1: C1.1, R1.2, U1.5; also elsewhere on the board
/J1.3: C2.1, R4.2, U1.3; also elsewhere on the board
/J1.8: C9.2, D1.2 (A), Q1.2 (D); also elsewhere on the board
/Main control/A: U5.11
/Main control/Selector drivers/Clock: U1.9, U4.9 (Q); also elsewhere on the board
/Main control/Selector drivers/~Clock: U4.8 (~Q); also elsewhere on the board
/Main control/Start punch: R6.2; also elsewhere on the board
/Main control/~Clutch: TP1.1, U4.4 (~S); also elsewhere on the board
/Main control/~Skip: R3.2, R8.2, TP2.1, U6.2; also elsewhere on the board
GND: C1.2, C2.2, C3.2, C4.2, C5.2, C6.2, C7.2, Q1.3 (S), R11.2, U4.2 (D), U4.12 (D); also elsewhere on the board
unnamed: C3.1, R6.1, TP22.1, U1.1
unnamed: C4.1, R8.1, U6.9
unnamed: C6.1, R10.1, U6.4
unnamed: C7.1, R13.1, U6.11
unnamed: C9.1, R15.1
unnamed: Q1.1 (G), R12.2
unnamed: R7.2, U6.13
unnamed: R10.2, U5.6
unnamed: R11.1, R12.1, TP4.1, U6.12
unnamed: R13.2, U1.8
unnamed: U1.2, U5.1, U5.2
unnamed: U1.11, U6.8
unnamed: U1.6, U4.3 (C)
unnamed: U1.13, U4.6 (~Q), U6.1
unnamed: C5.1, R9.2, U4.1 (~R), U4.13 (~R)
unnamed: U5.3, U5.4, U5.5, U6.3
Snubber: D1.1 (K); also elsewhere on the board

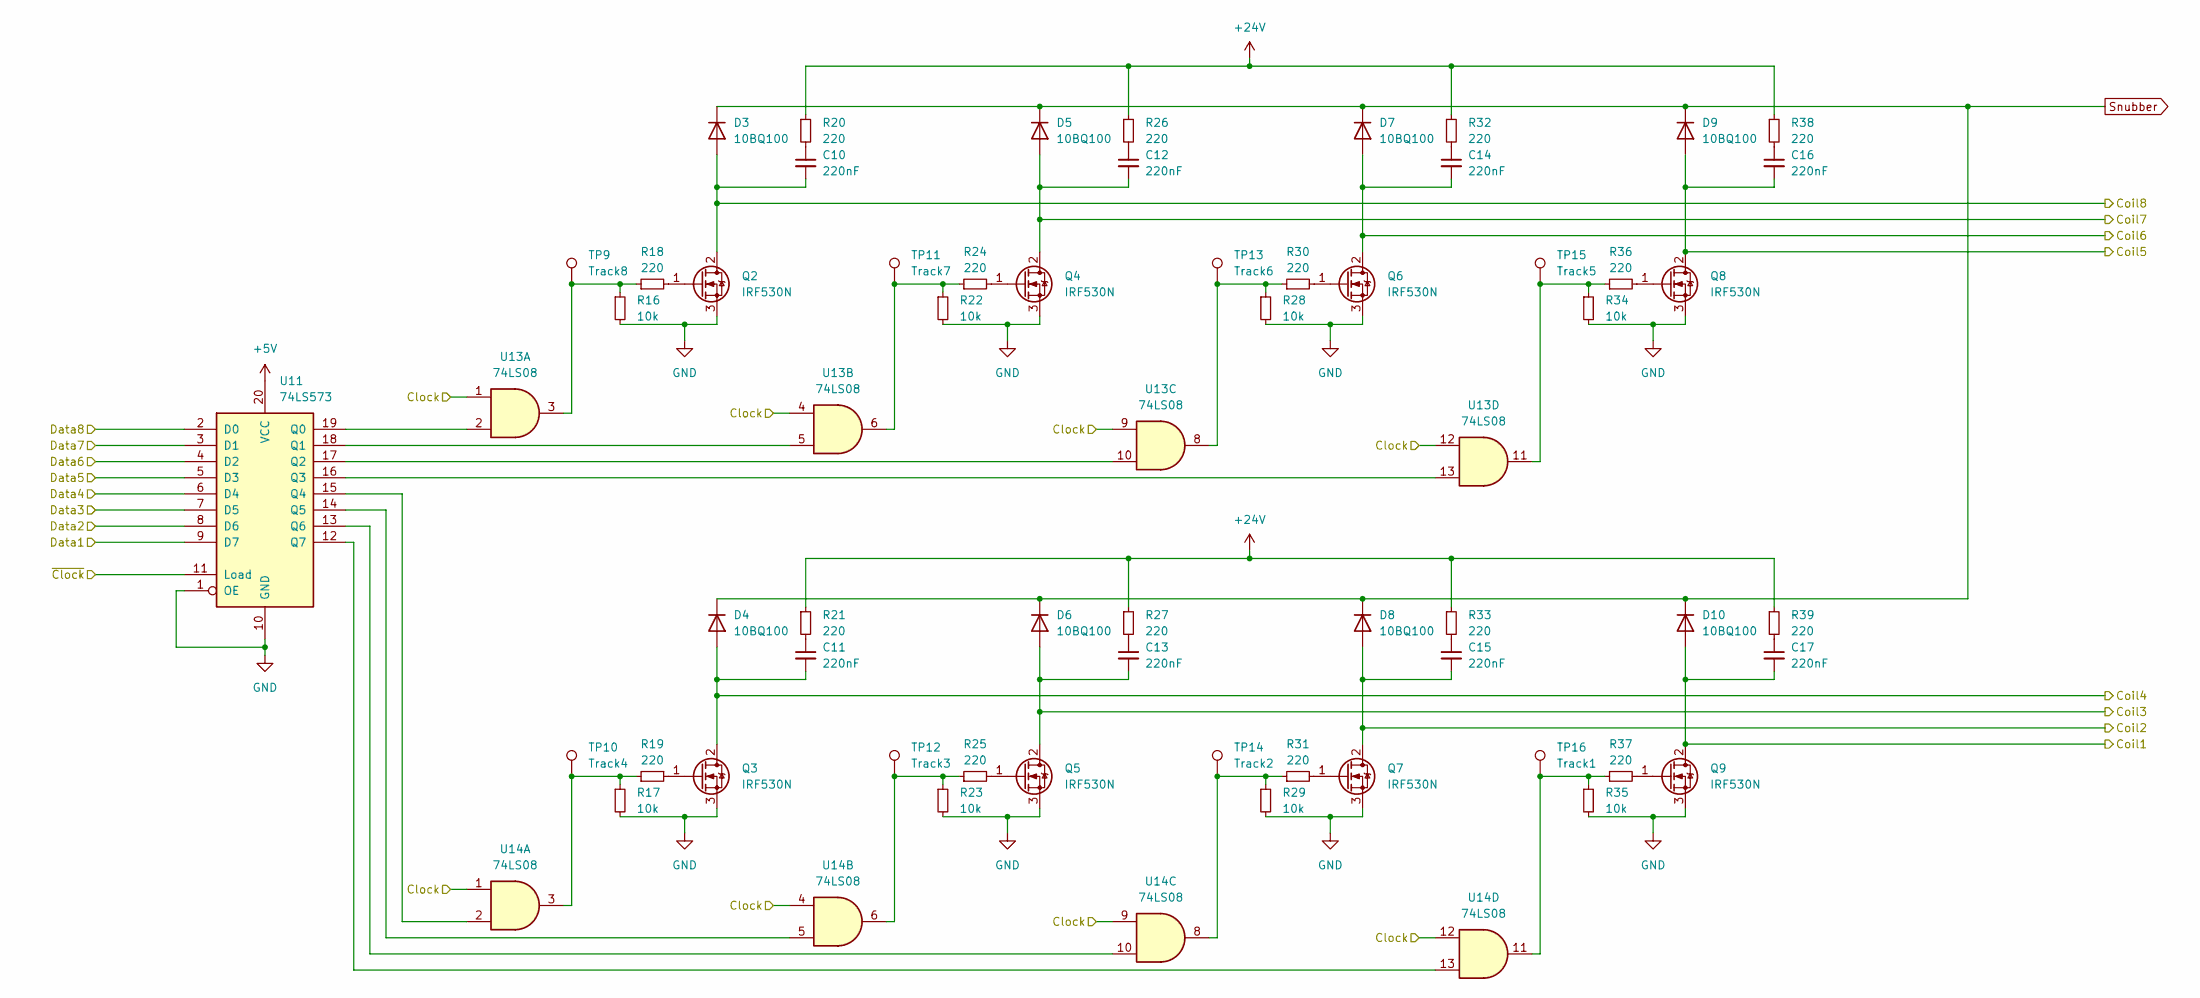
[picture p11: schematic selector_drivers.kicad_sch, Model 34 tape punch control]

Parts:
C10, C11, C12, C13, C14, C15, C16, C17: 220nF; C_0805_2012Metric_Pad1.18x1.45mm_HandSolder
D3, D4, D5, D6, D7, D8, D9, D10: 10BQ100; D_SMA-SMB_Universal_Handsoldering
Q2, Q3, Q4, Q5, Q6, Q7, Q8, Q9: IRF530N; TO-220-3_Vertical
R16, R17, R22, R23, R28, R29, R34, R35: 10k; R_0805_2012Metric_Pad1.20x1.40mm_HandSolder
R18, R19, R20, R21, R24, R25, R26, R27, R30, R31, R32, R33, R36, R37, R38, R39: 220; R_0805_2012Metric_Pad1.20x1.40mm_HandSolder
TP9: Track8; TestPoint_Loop_D2.54mm_Drill1.5mm_Beaded
TP10: Track4; TestPoint_Loop_D2.54mm_Drill1.5mm_Beaded
TP11: Track7; TestPoint_Loop_D2.54mm_Drill1.5mm_Beaded
TP12: Track3; TestPoint_Loop_D2.54mm_Drill1.5mm_Beaded
TP13: Track6; TestPoint_Loop_D2.54mm_Drill1.5mm_Beaded
TP14: Track2; TestPoint_Loop_D2.54mm_Drill1.5mm_Beaded
TP15: Track5; TestPoint_Loop_D2.54mm_Drill1.5mm_Beaded
TP16: Track1; TestPoint_Loop_D2.54mm_Drill1.5mm_Beaded
U11: 74LS573; SOIC-20W_7.5x12.8mm_P1.27mm
U13, U14: 74LS08; SOIC-14_3.9x8.7mm_P1.27mm

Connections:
+5V: U11.20 (VCC); also elsewhere on the board
+24V: R20.1, R21.1, R26.1, R27.1, R32.1, R33.1, R38.1, R39.1; also elsewhere on the board
/J1.18: C10.2, D3.2 (A), Q2.2 (D); also elsewhere on the board
/J1.19: C12.2, D5.2 (A), Q4.2 (D); also elsewhere on the board
/J1.20: C14.2, D7.2 (A), Q6.2 (D); also elsewhere on the board
/J1.21: C16.2, D9.2 (A), Q8.2 (D); also elsewhere on the board
/J1.22: C11.2, D4.2 (A), Q3.2 (D); also elsewhere on the board
/J1.23: C13.2, D6.2 (A), Q5.2 (D); also elsewhere on the board
/J1.24: C15.2, D8.2 (A), Q7.2 (D); also elsewhere on the board
/J1.25: C17.2, D10.2 (A), Q9.2 (D); also elsewhere on the board
/Main control/Selector drivers/Clock: U13.1, U13.4, U13.9, U13.12, U14.1, U14.4, U14.9, U14.12; also elsewhere on the board
/Main control/Selector drivers/~Clock: U11.11 (Load); also elsewhere on the board
/Main control/Track 1: U11.9 (D7); also elsewhere on the board
/Main control/Track 2: U11.8 (D6); also elsewhere on the board
/Main control/Track 3: U11.7 (D5); also elsewhere on the board
/Main control/Track 4: U11.6 (D4); also elsewhere on the board
/Main control/Track 5: U11.5 (D3); also elsewhere on the board
/Main control/Track 6: U11.4 (D2); also elsewhere on the board
/Main control/Track 7: U11.3 (D1); also elsewhere on the board
/Main control/Track 8: U11.2 (D0); also elsewhere on the board
GND: Q2.3 (S), Q3.3 (S), Q4.3 (S), Q5.3 (S), Q6.3 (S), Q7.3 (S), Q8.3 (S), Q9.3 (S), R16.2, R17.2, R22.2, R23.2, R28.2, R29.2, R34.2, R35.2, U11.1 (OE), U11.10 (GND); also elsewhere on the board
unnamed: C10.1, R20.2
unnamed: C11.1, R21.2
unnamed: C12.1, R26.2
unnamed: C13.1, R27.2
unnamed: C14.1, R32.2
unnamed: C15.1, R33.2
unnamed: C16.1, R38.2
unnamed: C17.1, R39.2
unnamed: Q2.1 (G), R18.2
unnamed: Q3.1 (G), R19.2
unnamed: Q4.1 (G), R24.2
unnamed: Q5.1 (G), R25.2
unnamed: Q6.1 (G), R30.2
unnamed: Q7.1 (G), R31.2
unnamed: Q8.1 (G), R36.2
unnamed: Q9.1 (G), R37.2
unnamed: R16.1, R18.1, TP9.1, U13.3
unnamed: R17.1, R19.1, TP10.1, U14.3
unnamed: R22.1, R24.1, TP11.1, U13.6
unnamed: R23.1, R25.1, TP12.1, U14.6
unnamed: R28.1, R30.1, TP13.1, U13.8
unnamed: R29.1, R31.1, TP14.1, U14.8
unnamed: R34.1, R36.1, TP15.1, U13.11
unnamed: R35.1, R37.1, TP16.1, U14.11
unnamed: U11.19 (Q0), U13.2
unnamed: U11.18 (Q1), U13.5
unnamed: U11.17 (Q2), U13.10
unnamed: U11.16 (Q3), U13.13
unnamed: U11.15 (Q4), U14.2
unnamed: U11.14 (Q5), U14.5
unnamed: U11.13 (Q6), U14.10
unnamed: U11.12 (Q7), U14.13
Snubber: D3.1 (K), D4.1 (K), D5.1 (K), D6.1 (K), D7.1 (K), D8.1 (K), D9.1 (K), D10.1 (K); also elsewhere on the board

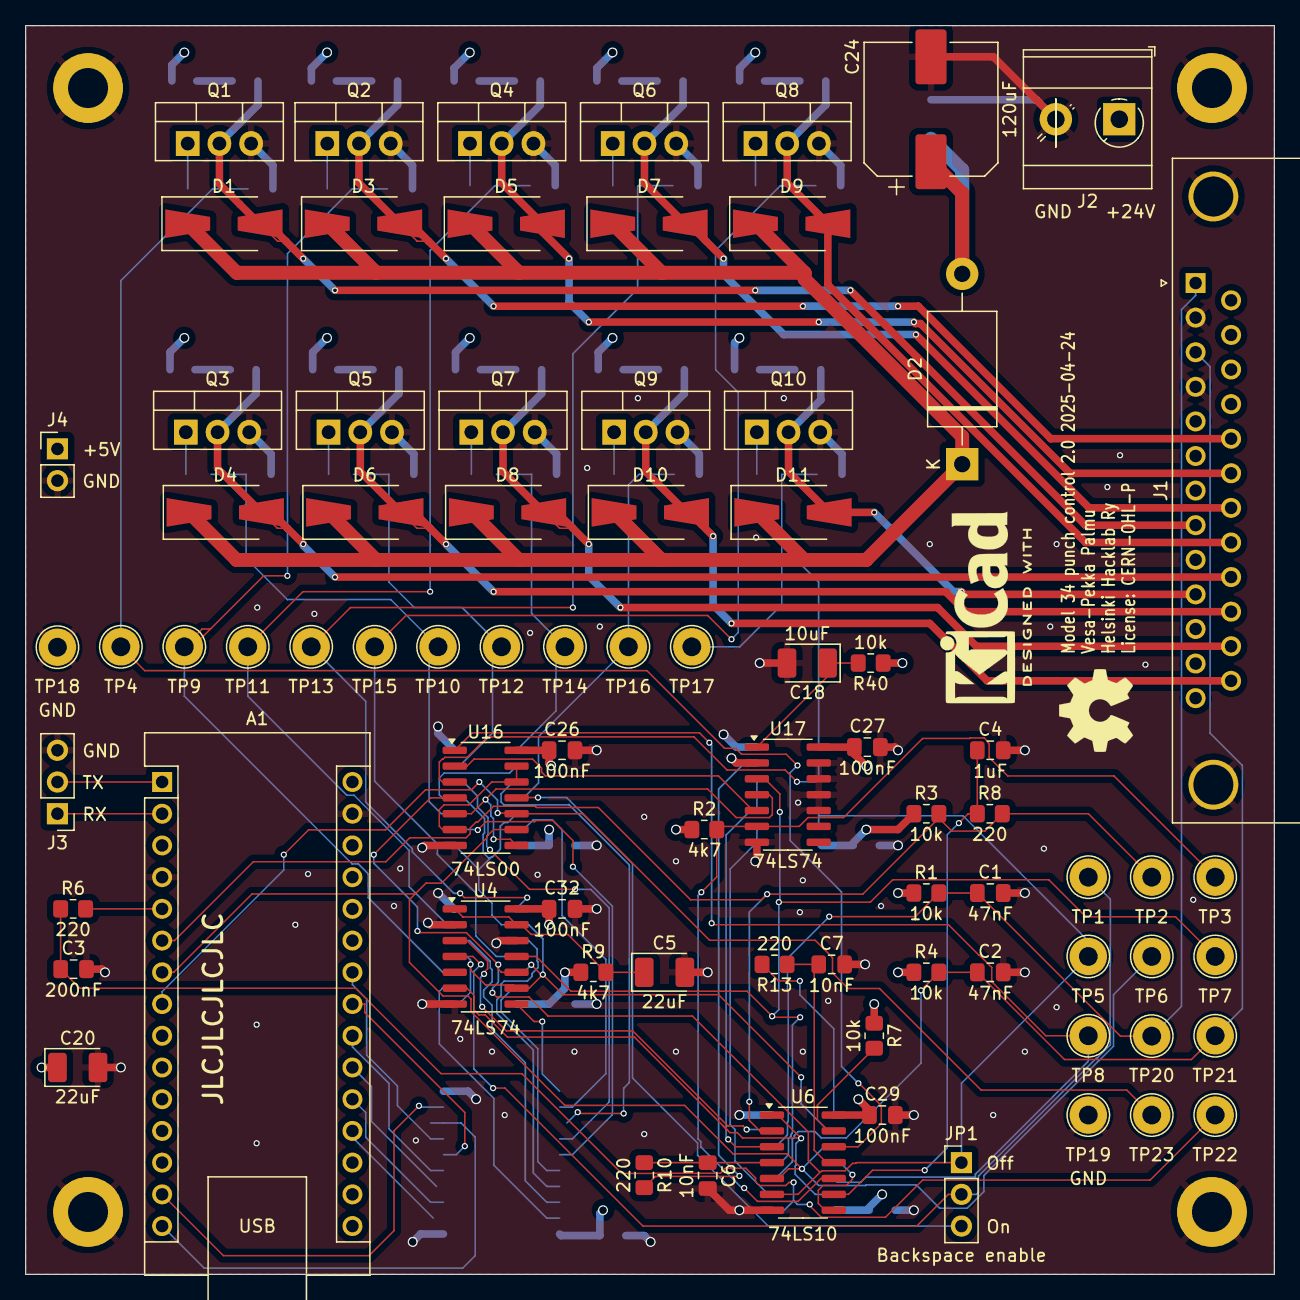
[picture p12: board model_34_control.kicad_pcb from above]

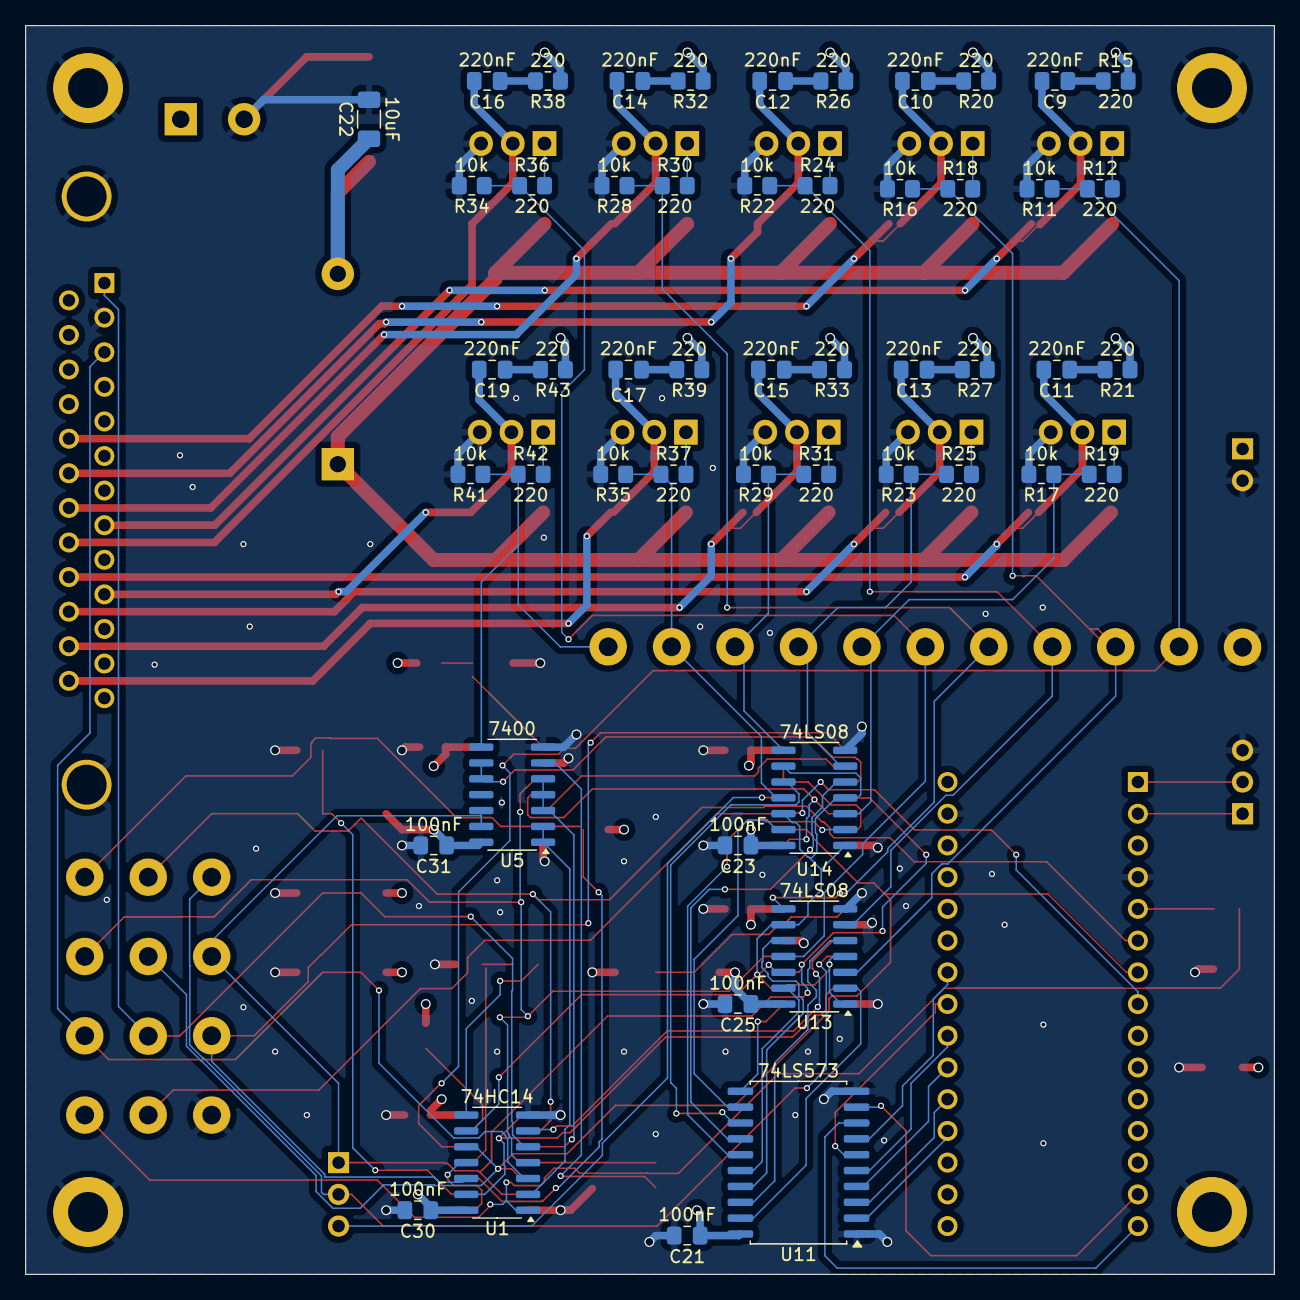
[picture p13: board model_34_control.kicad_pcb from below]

Board: 4 copper layers, 100.0 x 100.0 mm, 136 parts (51 on the bottom side), 94 nets.

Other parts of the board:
H1, H2, H3, H4: MountingHole_Pad; MountingHole_3.2mm_M3_DIN965_Pad
LOGO1: KiCad-Logo2_6mm_SilkScreen
LOGO2: OSHW-Symbol_6.7x6mm_SilkScreen

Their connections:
GND: H1.1, H2.1, H3.1, H4.1; also elsewhere on the board

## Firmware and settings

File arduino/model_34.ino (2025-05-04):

// Model 34 tape & card punch controller software
// Vesa-Pekka Palmu 2025
// Lisenced under the MIT lisence.

// Punch control pins
#define P_START 2
#define P_SKIP 3
#define P_BUSY 4
#define P_BACKSPACE 5

// Pins for data tracks
#define T_8 A0
#define T_7 A1
#define T_6 A2
#define T_5 A3
#define T_4 A4
#define T_3 A5
#define T_2 12
#define T_1 11

#define BUF_HIGH 32
#define S_IDLE 0
#define S_PUNCH 1
#define S_BUSY 2

#define XON 0x11
#define XOFF 0x13

uint8_t tracks[] = {T_1, T_2, T_3, T_4, T_5, T_6, T_7, T_8};

void setup() {
  // put your setup code here, to run once:

  Serial.begin(19200);

  // Initialize the punch control signals
  pinMode(P_START, OUTPUT);
  digitalWrite(P_START, LOW);
  pinMode(P_SKIP, OUTPUT);
  digitalWrite(P_SKIP, HIGH);
  pinMode(P_BACKSPACE, OUTPUT);
  digitalWrite(P_BACKSPACE, LOW);
  
  pinMode(P_BUSY, INPUT);
  
  // Led
  pinMode(13, OUTPUT);

  // Data track outputs
  for (uint8_t i = 0; i < 8; i++) {
    pinMode(tracks[i], OUTPUT);
    digitalWrite(tracks[i], HIGH);
  }
  Serial.write("S");
}

// Punch a character and set state to busy
void startPunch(uint8_t data) {
  // Punch data bits
  for (uint8_t i = 0; i < 8; i++) {
    digitalWrite(tracks[i], (data >> i) & 1);
  }

  // Start the punch
  delay(1);
  digitalWrite(P_START, HIGH);
  delay(1);
  digitalWrite(P_START, LOW);
  delay(1);
}

void loop() {
  if (!Serial.available()) {
    // No bytes, send XON to request input
    Serial.write(XON);
  }

  if (Serial.available() > BUF_HIGH) {
    // Buffer is almost full, send XOFF until we have punched everything
    Serial.write(XOFF);
  }

  if (digitalRead(P_BUSY) == HIGH) {
      if (Serial.available()) {
        // Punch is idle and we have data, punch it
        startPunch(Serial.read());
      }
  }
}
